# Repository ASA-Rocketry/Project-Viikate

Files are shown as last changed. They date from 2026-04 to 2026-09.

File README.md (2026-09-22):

# Project Viikate

1. Clone this repository using `git clone https://github.com/ASA-Rocketry/Project-Viikate`.
2. Open the repository in your preferred editor or just `cd` into it.
3. Run `pip install pre-commit` to install the pre-commit hook manager.
4. Run `pre-commit install --hook-type commit-msg` to activate all the local checks.
5. Run `meson setup code/build code --wipe` to generate the project compilation commands.
6. Run `meson compile -C code/build` to compile the binary. The final binary will be in `code/build/firmware/firmware`.

## Structure

```
project-viikate/
  cad/          -- the fusion files for the structure of the rocket
  code/         -- firmware, simulations and other adjacent software
    firmware/   -- the actual firmware that goes on the rocket
    dashboard/
  docs/         -- textual documentation related to the operations of the project
  minutes/      -- meeting notes
  pcb/          -- electronics, pinouts and the core PCB
```

## Software

## Style Choices

- For details on how to style your code refer to [RocketStyle](./code/README.md).
- For details on how to style your mechanical designs refer to [Mechanical Design Guide for Aalto Space Association Projects with Fusion](./cad/README.md).
- Folder names should follow `kebab-case` unless mandated by the style guide of the specific piece of software.
- Files should follow `snake_case` unless mandated by the style guide of a specific piece of software.

## Testing Policy

The priority of tests is strictly in this order:

0. Structural failures.
1. Serialization/deserialization.
2. Unit conversions.
3. Sensor fusion edgecases.
4. State machine transitions.
5. Numerical stability.
6. Watchdog/fault recovery.

Notice how getters and setters are not included. They are not important.

## How to make Git less painful

- Use rebases instead of merges. Merges pollute history, rebases straighten it back out.
- Don't commit stuff that is not supposed to be `diff`-ed. If you can't meaningfully interpret a file changing across time it should not be in git.
- Don't commit caches. Temporary files, output binaries, stuff like that.
- A commit message should follow the strict `type(scope): Message` format. This is needed to make the scope of the changes easier to understand. For example: `feat(gnc): Add the barrel roll logic`. The accepted types are as follows:
  - `feat` - a new feature, functionality that was previously missing.
  - `fix` - a fix to a bug that was causing trouble.
  - `style` - making some part of the code adhere to a style.
  - `docs` - adding documentation, amending typos.
  - `refactor` - making an old piece of code less ugly.
  - `chore` - reordering files, deleting stuff that shouldn't be tracked, etc.
- The commit text should read as what it does when applied. Not `added more tests`, but `add more tests`.
- Do not include OS-specific files in git. To exclude file locally you can add it to the `.git/info/exclude` file.

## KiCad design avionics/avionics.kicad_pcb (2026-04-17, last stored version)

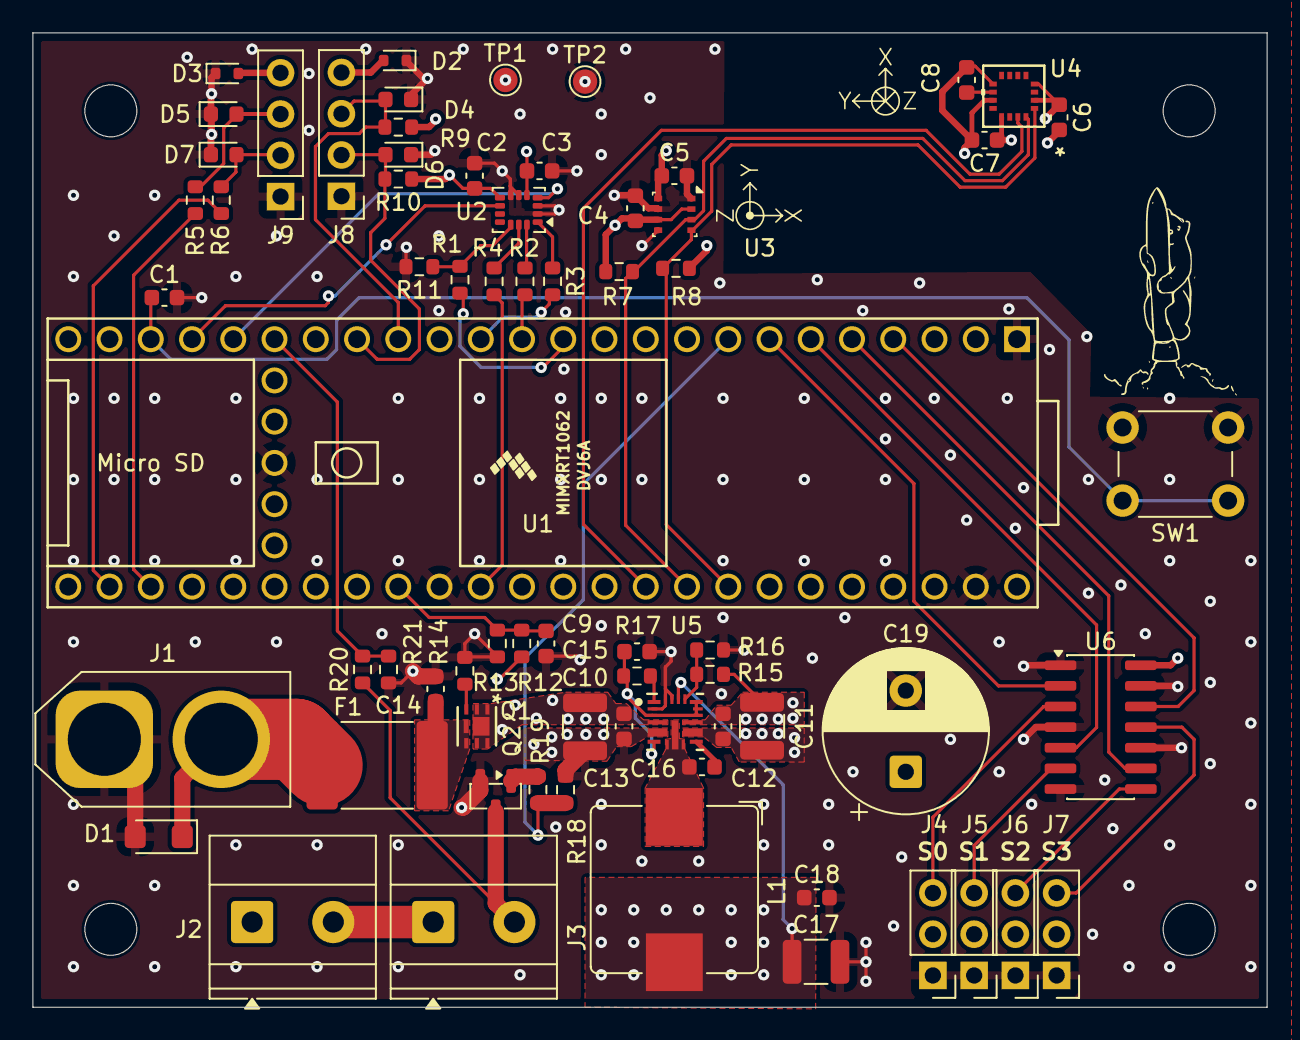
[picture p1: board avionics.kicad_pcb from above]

Board: 4 copper layers, 76.0 x 60.0 mm, 70 parts (0 on the bottom side), 49 nets.

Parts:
C1, C2, C3, C4, C5, C6, C7, C9, C14, C16: 100n; C_0603_1608Metric
C8: 10u; C_0603_1608Metric
C10, C11: 22u; C_1210_3225Metric
C12, C13, C15, C18: 1u; C_0603_1608Metric
C17: 47u; C_1210_3225Metric
C19: 1000u; CP_Radial_D10.0mm_P5.00mm
D1: SMF10A; D_SMF
D2, D3: CPDH5V0U; D_SOD-523
D4, D5, D6, D7: CPDUR5V0-HF; D_0603_1608Metric
F1: Littelfuse 2920L400; Fuse_2920_7451Metric
J1: XT60M; AMASS_XT60-M_1x02_P7.20mm_Vertical
J2, J3: 1x2_header; TerminalBlock_Phoenix_MKDS-1,5-2_1x02_P5.00mm_Horizontal
J4, J5, J6, J7: 1x3_header; PinHeader_1x03_P2.54mm_Vertical
J8, J9: Conn_01x04_Pin; PinHeader_1x04_P2.54mm_Vertical
L1: 300n; L_Bourns_SRP1038C_10.0x10.0mm
M3: MountingHole_3.2mm_M3
Q1: RF4C050AP; TRANS_RF4C_ROM
Q2: AO3400A; SOT-23
R1, R2, R3, R4, R5, R6, R19: 33; R_0603_1608Metric
R7, R8, R9, R10: 2.7k; R_0603_1608Metric
R11, R18: 100k; R_0603_1608Metric
R12, R20: 56k; R_0603_1608Metric
R13, R21: 33k; R_0603_1608Metric
R14: 47k; R_0603_1608Metric
R15: 37.4k; R_0603_1608Metric
R16, R17: 10k; R_0603_1608Metric
SW1: 6x6mm Switch; SW_PUSH_6mm
TP1: TP_3.3V; TestPoint_Pad_D1.5mm
TP2: TP_GND; TestPoint_Pad_D1.5mm
U1: Teensy4.1; Teensy41
U2: ISM330DHCX; LGA-14_3x2.5mm_P0.5mm_LayoutBorder3x4y
U3: BME280; Bosch_LGA-8_2.5x2.5mm_P0.65mm_ClockwisePinNumbering
U4: MMC5983MA; MMC5983MA_MEM
U5: TPS548B23VANR; VAN0019A-MFG
U6: 74AHCT125; SOIC-14_3.9x8.7mm_P1.27mm

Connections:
+3.3V: C2.1, C3.2, C4.1, C5.1, C6.1, C7.1, R7.1, R8.1, R9.1, R10.1, TP1.1, U1.46 (3V3), U1.51 (3V3), U2.5 (VDDIO), U2.8 (VDD), U3.2 (CSB), U3.6 (VDDIO), U3.8 (VDD), U4.2 (VDD), U4.4 (SPI_CS), U4.13 (VDDIO)
+5V: C17.1, C18.1, C19.1, J4.2, J5.2, J6.2, J7.2, L1.2, U1.48 (VIN), U5.17 (VOS_FB), U6.14 (VCC)
+BATT: C10.1, C11.1, C12.1, C13.1, J2.1, Q1.1, Q1.2, Q1.5, Q1.6, Q1.7, R12.1, R15.1, U5.4 (VIN), U5.12 (VIN)
/BAT_VOLTAGE: C9.1, R12.2, R13.1, U1.33 (41_A17)
/I2C_OUT_SCL: D4.2 (A2), J8.3, R9.2, U1.16 (24_A10_TX6_SCL2)
/I2C_OUT_SDA: D6.2 (A2), J8.2, R10.2, U1.17 (25_A11_RX6_SDA2)
/I2C_SCL: R8.2, U1.41 (19_A5_SCL), U3.4 (SCK), U4.1 (SCL/SPI_SCK)
/I2C_SDA: R7.2, U1.40 (18_A4_SDA), U3.3 (SDI), U4.16 (SDA/SPI_SDI)
/INT_ACC: U1.20 (28_RX7), U2.4 (INT1)
/INT_GYR: U1.21 (29_TX7), U2.9 (INT2)
/Magnetometer/INT: U1.39 (17_A3_TX4_SDA1), U4.15 (INT)
/PSU/BAT_CONN+: D1.1 (A1), F1.1, J1.2
/PYRO_0: R18.1, R19.2, U1.8 (6_OUT1D)
/PYRO_0_CONT: R20.2, R21.1, U1.19 (27_A13_SCK1)
/Pyro_and_servos/ARM_Vout: J2.2, J3.1
/Pyro_and_servos/PYRO_0_GATE: Q2.1 (G), R19.1
/Pyro_and_servos/PYRO_0_Vout: J3.2, Q2.3 (D), R20.1
/Pyro_and_servos/SERVO_0: J4.3, U6.3
/Pyro_and_servos/SERVO_1: J5.3, U6.6
/Pyro_and_servos/SERVO_2: J6.3, U6.8
/Pyro_and_servos/SERVO_3: J7.3, U6.11
/SERVO_0_PWM: U1.7 (5_IN2), U6.2
/SERVO_1_PWM: U1.6 (4_BCLK2), U6.5
/SERVO_2_PWM: U1.5 (3_LRCLK2), U6.9
/SERVO_3_PWM: U1.4 (2_OUT2), U6.12
/SPI_CS: R1.1, R11.1, U2.12 (CS)
/SPI_MISO: R3.1, U2.1 (SDO/SA0)
/SPI_MOSI: R2.1, U2.14 (SDA)
/SPI_SCK: R4.2, U2.13 (SCL)
/SW_GUIDANCE: C1.1, SW1.1, U1.22 (30_CRX3)
/UART_RX: D7.2 (A2), J9.2, R6.2
/UART_TX: D5.2 (A2), J9.3, R5.2
GND: C1.2, C2.2, C3.1, C4.2, C5.2, C6.2, C7.2, C8.1, C9.2, C10.2, C11.2, C12.2, C13.2, C14.2, C15.2, C17.2, C18.2, C19.2, D1.2 (A2), D2.1 (K), D3.1 (K), D4.1 (A1), D5.1 (A1), D6.1 (A1), D7.1 (A1), J1.1, J4.1, J5.1, J6.1, J7.1, J8.1, J9.1, Q2.2 (S), R11.2, R13.2, R14.2, R16.2, R18.2, R21.2, SW1.2, TP2.1, U1.1 (GND), U1.34 (GND), U1.47 (GND), U1.52 (GND), U2.2 (SDx), U2.3 (SCx), U2.6 (GND), U2.7 (GND), U3.1 (GND), U3.5 (SDO), U3.7 (GND), U4.9 (GND), U4.11 (GND), U5.2 (CFG2), U5.5 (PGND), U5.11 (PGND), U5.18 (GOS), U5.19 (AGND), U6.1, U6.4, U6.7 (GND), U6.10, U6.13
unnamed: C14.1, F1.2, Q1.4, Q1.8
unnamed: C16.2, L1.1, U5.7 (SW), U5.8 (SW), U5.9 (SW)
unnamed: D2.2 (A), J8.4
unnamed: D3.2 (A), J9.4
unnamed: Q1.3, R14.1
unnamed: R1.2, U1.12 (10_CS_MQSR)
unnamed: R2.2, U1.13 (11_MOSI_CTX1)
unnamed: R3.2, U1.14 (12_MISO_MQSL)
unnamed: R4.1, U1.35 (13_SCK_LED)
unnamed: R6.1, U1.26 (34_RX8)
unnamed: R5.1, U1.27 (35_TX8)
unnamed: C8.2, U4.10 (CAP)
unnamed: C16.1, U5.10 (BST)
unnamed: C15.1, R17.2, U5.3 (CFG1), U5.6 (VCC), U5.13 (CFG3), U5.14 (CFG4), U5.15 (CFG5)
unnamed: R15.2, R16.1, U5.16 (EN)
unnamed: R17.1, U5.1 (PG)

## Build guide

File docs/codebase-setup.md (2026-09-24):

# Codebase setup guide

Within this guide we will go over the steps of setting up the Project Viikate
codebase. You will need approximately **2 hours of time** to download and setup
everything necessary to build and flash the firmware for the avioncis unit.

## Prerequisites

Before we setup the toolchain you will need to install nix, the tool we use for
installing dependencies. While it is possible to avoid using nix, it can be
quite difficult.

### Windows users

People working on Windows will need to setup the [Windows Subsystem for Linux (WSL)](https://learn.microsoft.com/en-us/windows/wsl/install).
If you are using VSCode, it might be useful to install the [WSL Extension](https://code.visualstudio.com/docs/remote/wsl).
In order to flash the avionics board, you will have to [pass through the USB device to the VM](https://learn.microsoft.com/en-us/windows/wsl/connect-usb).

After installing WSL, you should edit the `/etc/wsl.conf` and add the following if it isn't present already (new WSL installs have this by default):
```ini
[boot]
systemd=true
```

Finally, restart the WSL virtual machine.

### Installing nix

In order to install nix, you want to [visit the nix download page](https://nixos.org/download/#nix-install-windows)
and copy and run the **multi-user installation** in the command line.

You will have to enable nix flakes by adding this to `/etc/nix/nix.conf`:
```ini
experimental-features = nix-command flakes
```

## Seting up the codebase

Quick way:
```bash
nix develop
cd code
west init -l .
west update
west zephyr-export
west build -b teensy41 app
```

Flashing:
```bash
west flash
```

Flashing and opening a serial console (the `/dev/ttyACM0` part might be different based on your system, asking ChatGPT will help if you can't find it):
```bash
west flash && sleep 1 && picocom -b 115200 /dev/ttyACM0
```

When you open a new shell (i.e. when you open VSCode for the first time), you always have to run:
```bash
nix develop
```

This is to install any dependencies.

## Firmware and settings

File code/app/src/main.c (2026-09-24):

#include <arm_math.h>
#include <assert.h>
#include <math.h>
#include <stdint.h>
#include <zephyr/drivers/pwm.h>
#include <zephyr/drivers/sensor.h>
#include <zephyr/kernel.h>
#include <zephyr/sys/printk.h>

#include "dsp/controller_functions.h"
#include "dsp/filtering_functions.h"
#include "guidance/filters.h"
#include "guidance/kalman.h"
#include "guidance/pid.h"
#include "math/linmath.h"
#include "sensors.h"
#include "servo.h"
#include "zephyr/sys/time_units.h"

#define IMU_NODE DT_NODELABEL(imu)
#define BAROMETER_NODE DT_NODELABEL(barometer)

static const struct device *imu = DEVICE_DT_GET(IMU_NODE);
static const struct device *barometer = DEVICE_DT_GET(BAROMETER_NODE);

#define STEP PWM_USEC(10)

enum direction {
    DOWN,
    UP,
};

#define TASK_BAROMETER_READ_STACK_SIZE 4096
#define TASK_BAROMETER_READ_PRIORITY 1

K_THREAD_DEFINE(
    task_barometer_read_thread_id,
    TASK_BAROMETER_READ_STACK_SIZE,
    task_barometer_read,
    &barometer,
    NULL,
    NULL,
    TASK_BAROMETER_READ_PRIORITY,
    0,
    0
);

static int sweep_servo(const servo_t servo) {
    float angle = -90.0f;  // start at minimum position
    enum direction dir = UP;
    int ret;

    printk("Servomotor control (angle based)\n");

    if (!pwm_is_ready_dt(&servo.spec)) {
        printk("Error: PWM device %s is not ready\n", servo.spec.dev->name);
        return -ENODEV;
    }

    while (1) {
        ret = servo_set_angle(servo, angle);
        if (ret < 0) {
            printk("Error %d: failed to set angle %.1f\n", ret, (double)angle);
            return ret;
        }

        // Step size = degrees per iteration
        const float step_size = 1.0f;

        if (dir == UP) {
            angle += step_size;
            if (angle >= 90.0f) {
                angle = 90.0f;
                dir = DOWN;
            }
        } else {
            angle -= step_size;
            if (angle <= -90.0f) {
                angle = -90.0f;
                dir = UP;
            }
        }

        k_sleep(K_MSEC(20));  // Smooth sweep speed
    }

    return 0;
}

double pressure_to_altitude(double pressure_pa) {
    const double P0 = 101325.0;  // Sea level pressure (Pa)
    const double T0 = 288.15;  // Sea level temperature (K)
    const double L = 0.0065;  // Temperature lapse rate (K/m)
    const double g = 9.80665;  // Gravity (m/s²)
    const double R = 287.05;  // Specific gas constant (J/(kg·K))

    // Barometric formula: h = (T0 / L) * (1 - (P / P0)^(R*L/g))
    double exponent = (R * L) / g;
    double altitude = (T0 / L) * (1.0 - pow(pressure_pa / P0, exponent));

    return altitude;
}

void print_acceleration(const imu_sample_t *sample) {
    printf(
        "Acceleration [m/s²]: X=%f, Y=%f, Z=%f\n",
        (double)sample->acceleration[0],
        (double)sample->acceleration[1],
        (double)sample->acceleration[2]
    );
}

void transform_coords(imu_sample_t *imu_sample) {
    vec3 acc_old;
    vec3 gyro_old;
    vec3_dup(acc_old, imu_sample->acceleration);
    vec3_dup(gyro_old, imu_sample->angular_rate);

    imu_sample->acceleration[0] = -acc_old[2];
    imu_sample->acceleration[1] = acc_old[1];
    imu_sample->acceleration[2] = acc_old[0];

    imu_sample->angular_rate[0] = -gyro_old[2];
    imu_sample->angular_rate[1] = gyro_old[1];
    imu_sample->angular_rate[2] = gyro_old[0];
}

LINMATH_H_FUNC float quat_get_roll(quat const q) {
    float x = q[0];
    float y = q[1];
    float z = q[2];
    float w = q[3];

    float siny_cosp = 2.f * (w * z + x * y);
    float cosy_cosp = 1.f - 2.f * (y * y + z * z);

    return atan2f(siny_cosp, cosy_cosp);
}

int main(void) {
    barometer_init(barometer);
    imu_init(imu);

    imu_sample_t imu_sample;
    barometer_sample_t baro_sample;
    int ret;

    assert(imu_filter != NULL);

    float drift_last = 0.0f;

    vec3 avg_accel = {0}, avg_gyro = {0};

    vec3 g = {0};
#define AVG_COUNT 256
    for (int k_idx = 0; k_idx < AVG_COUNT; ++k_idx) {
        ret = k_msgq_get(&imu_msgq, &imu_sample, K_FOREVER);
        transform_coords(&imu_sample);
        vec3_add(g, g, imu_sample.acceleration);
    }
    vec3_scale(g, g, 1.0f / AVG_COUNT);

    kalman_filter_t k = kalman_init(g);

#define AVG_COUNT 256
    for (int k_idx = 0; k_idx < AVG_COUNT; ++k_idx) {
        ret = k_msgq_get(&imu_msgq, &imu_sample, K_FOREVER);
        transform_coords(&imu_sample);
        vec3 a;
        vec3_sub(a, imu_sample.acceleration, g);

        vec3_add(avg_accel, avg_accel, a);
        vec3_add(avg_gyro, avg_gyro, imu_sample.angular_rate);
    }

    vec3_scale(avg_accel, avg_accel, 1.0f / AVG_COUNT);
    vec3_scale(avg_gyro, avg_gyro, 1.0f / AVG_COUNT);

    vec3_dup(k.gyroscope_bias, avg_gyro);
    vec3_dup(k.accelerometer_bias, avg_accel);

    float base_altitude = 0.0f;
    for (int k_idx = 0; k_idx < 8; ++k_idx) {
        ret = k_msgq_get(&barometer_msgq, &baro_sample, K_FOREVER);

        base_altitude += pressure_to_altitude((double)baro_sample.pressure);
    }

    base_altitude *= 1.0f / 8;

    uint32_t loop_counter = 0;
    uint64_t time = 0;
    int loops = 0;

    roll_control_reset();

    while (1) {
        uint64_t start = k_ticks_to_ns_floor64(k_uptime_ticks());

        /* Read IMU if data is available */
        while ((ret = k_msgq_get(&imu_msgq, &imu_sample, K_NO_WAIT)) == 0) {
            transform_coords(&imu_sample);
            ekf_predict(&k, imu_sample);
            loops++;
        }

        time += k_ticks_to_ns_floor64(k_uptime_ticks()) - start;

        while ((ret = k_msgq_get(&barometer_msgq, &baro_sample, K_NO_WAIT))
               == 0) {
            float altitude = (float)pressure_to_altitude(baro_sample.pressure)
                - base_altitude;
            k.position[1] = altitude;
        }

        /* Print state every 500 iterations (~500 ms at 1 kHz) */
        if (loop_counter % 500 == 0) {
            printk(
                "loops: %d total_time: %f time_per_kalman: %f\n",
                loops,
                (double)((float)time * 1e-9f),
                (double)((float)time * 1e-9f / (float)(loops > 0 ? loops : 1))
            );
            printk(
                "STATE:\n"
                "    pos = [%.3f, %.3f, %.3f]\n"
                "    vel = [%.3f, %.3f, %.3f]\n"
                "    ori = [%.4f, %.4f, %.4f, %.4f]\n"
                "    ang_vel = [%.4f, %.4f, %.4f]\n"
                "    acc_bias = [%.4f, %.4f, %.4f]\n"
                "    gyro_bias = [%.4f, %.4f, %.4f]\n"
                "    g = %.4f\n"
                "    t_last = %llu ns\n",
                (double)k.position[0],
                (double)k.position[1],
                (double)k.position[2],
                (double)k.velocity[0],
                (double)k.velocity[1],
                (double)k.velocity[2],
                (double)k.orientation[0],
                (double)k.orientation[1],
                (double)k.orientation[2],
                (double)k.orientation[3],
                (double)k.angular_velocity[0],
                (double)k.angular_velocity[1],
                (double)k.angular_velocity[2],
                (double)k.accelerometer_bias[0],
                (double)k.accelerometer_bias[1],
                (double)k.accelerometer_bias[2],
                (double)k.gyroscope_bias[0],
                (double)k.gyroscope_bias[1],
                (double)k.gyroscope_bias[2],
                (double)k.gravity,
                (unsigned long long)k.last_measurement_timestamp_ns
            );
            loops = 0;
        }

        static uint64_t last_roll_update_ns;

        if (loop_counter % 20 == 0) {
            uint64_t now = k_ticks_to_ns_floor64(k_uptime_ticks());
            float dt = last_roll_update_ns == 0
                ? 0.02f
                : (float)(now - last_roll_update_ns) * 1e-9f;
            last_roll_update_ns = now;

            roll_control_update(quat_get_roll(k.orientation), 0.0f, dt);
        }

        loop_counter++;
        k_sleep(K_MSEC(1));  // 1 kHz update rate
    }
}

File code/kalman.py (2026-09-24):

import serial
import re
import math
from collections import deque
import numpy as np
import matplotlib.pyplot as plt
import matplotlib.animation as animation
from matplotlib.gridspec import GridSpec
from mpl_toolkits.mplot3d import Axes3D
import threading


class KalmanVisualizer:
    def __init__(self, port="/dev/ttyACM0", baudrate=115200):
        self.port = port
        self.baudrate = baudrate
        self.serial = None
        self.max_history = 200

        self.history = {
            "pos": deque(maxlen=self.max_history),
            "vel": deque(maxlen=self.max_history),
            "euler": deque(maxlen=self.max_history),
            "ori": deque(maxlen=self.max_history),
            "ang_vel": deque(maxlen=self.max_history),
            "acc_bias": deque(maxlen=self.max_history),
            "gyro_bias": deque(maxlen=self.max_history),
            "time_per_kalman": deque(maxlen=self.max_history),
        }

        self.setup_plots()

    def connect(self):
        try:
            self.serial = serial.Serial(self.port, self.baudrate, timeout=1)
            print(f"Connected to {self.port}")
            return True
        except Exception as e:
            print(f"Failed to connect: {e}")
            return False

    def quaternion_to_euler(self, quat):
        """Convert quaternion [qx, qy, qz, qw] to Euler angles (degrees)"""
        qx, qy, qz, qw = quat

        sinr_cosp = 2 * (qw * qx + qy * qz)
        cosr_cosp = 1 - 2 * (qx * qx + qy * qy)
        roll = math.atan2(sinr_cosp, cosr_cosp)

        sinp = 2 * (qw * qy - qz * qx)
        pitch = math.asin(min(1, max(-1, sinp)))

        siny_cosp = 2 * (qw * qz + qx * qy)
        cosy_cosp = 1 - 2 * (qy * qy + qz * qz)
        yaw = math.atan2(siny_cosp, cosy_cosp)

        return [math.degrees(roll), math.degrees(pitch), math.degrees(yaw)]

    def quaternion_to_rotation_matrix(self, quat):
        """Convert quaternion to 3x3 rotation matrix"""
        qx, qy, qz, qw = quat

        R = np.array(
            [
                [
                    1 - 2 * (qy**2 + qz**2),
                    2 * (qx * qy - qz * qw),
                    2 * (qx * qz + qy * qw),
                ],
                [
                    2 * (qx * qy + qz * qw),
                    1 - 2 * (qx**2 + qz**2),
                    2 * (qy * qz - qx * qw),
                ],
                [
                    2 * (qx * qz - qy * qw),
                    2 * (qy * qz + qx * qw),
                    1 - 2 * (qx**2 + qy**2),
                ],
            ]
        )

        return R

    def setup_plots(self):
        """Setup matplotlib dashboard"""
        self.fig = plt.figure(figsize=(18, 10))
        self.fig.suptitle("Kalman Filter State Monitor", fontsize=16, fontweight="bold")

        gs = GridSpec(3, 4, figure=self.fig, hspace=0.3, wspace=0.3)

        self.ax_3d = self.fig.add_subplot(gs[0:2, 0], projection="3d")
        self.ax_pos = self.fig.add_subplot(gs[0, 1:3])
        self.ax_vel = self.fig.add_subplot(gs[1, 1:3])
        self.ax_euler = self.fig.add_subplot(gs[2, 1:3])

        self.ax_ang_vel = self.fig.add_subplot(gs[0, 3])
        self.ax_acc_bias = self.fig.add_subplot(gs[1, 3])
        self.ax_gyro_bias = self.fig.add_subplot(gs[2, 3])

        self.ax_stats = self.fig.add_axes([0.02, 0.02, 0.15, 0.15])
        self.ax_stats.axis("off")
        self.stats_text = self.ax_stats.text(
            0,
            1,
            "Waiting for data...",
            transform=self.ax_stats.transAxes,
            fontsize=9,
            verticalalignment="top",
            fontfamily="monospace",
        )

        self.ax_3d.set_xlabel("X")
        self.ax_3d.set_ylabel("Y")
        self.ax_3d.set_zlabel("Z")
        self.ax_3d.set_title("3D Orientation")
        self.ax_3d.set_xlim([-1.5, 1.5])
        self.ax_3d.set_ylim([-1.5, 1.5])
        self.ax_3d.set_zlim([-1.5, 1.5])

    def draw_3d_frame(self, ax, rotation_matrix):
        """Draw coordinate frame on 3D axis"""
        ax.clear()

        origin = np.array([0, 0, 0])

        x_axis = np.array([1, 0, 0])
        y_axis = np.array([0, 1, 0])
        z_axis = np.array([0, 0, 1])

        x_rotated = rotation_matrix @ x_axis
        y_rotated = rotation_matrix @ y_axis
        z_rotated = rotation_matrix @ z_axis

        ax.quiver(
            0,
            0,
            0,
            x_rotated[0],
            x_rotated[1],
            x_rotated[2],
            color="r",
            arrow_length_ratio=0.2,
            linewidth=2.5,
            label="X",
        )
        ax.quiver(
            0,
            0,
            0,
            y_rotated[0],
            y_rotated[1],
            y_rotated[2],
            color="g",
            arrow_length_ratio=0.2,
            linewidth=2.5,
            label="Y",
        )
        ax.quiver(
            0,
            0,
            0,
            z_rotated[0],
            z_rotated[1],
            z_rotated[2],
            color="b",
            arrow_length_ratio=0.2,
            linewidth=2.5,
            label="Z",
        )

        ax.set_xlabel("X")
        ax.set_ylabel("Y")
        ax.set_zlabel("Z")
        ax.set_xlim([-1.5, 1.5])
        ax.set_ylim([-1.5, 1.5])
        ax.set_zlim([-1.5, 1.5])
        ax.set_title("3D Orientation")
        ax.legend(fontsize=10)

    def parse_state(self, lines):
        """Parse STATE block from list of lines"""
        state = {}

        for line in lines:
            line = line.strip()
            if not line or line.startswith("STATE"):
                continue

            if "=" in line:
                key, value = line.split("=", 1)
                key = key.strip()
                value = value.strip()

                try:
                    if "[" in value and "]" in value:
                        nums = re.findall(r"-?\d+\.?\d*", value)
                        state[key] = [float(n) for n in nums]
                    else:
                        state[key] = float(value)
                except ValueError:
                    pass

        return state

    def update_data(self, state, time_per_kalman):
        """Add new state to history"""
        if "pos" in state:
            self.history["pos"].append(state["pos"])
        if "vel" in state:
            self.history["vel"].append(state["vel"])
        if "ori" in state:
            self.history["ori"].append(state["ori"])
            euler = self.quaternion_to_euler(state["ori"])
            self.history["euler"].append(euler)
        if "ang_vel" in state:
            self.history["ang_vel"].append(state["ang_vel"])
        if "acc_bias" in state:
            self.history["acc_bias"].append(state["acc_bias"])
        if "gyro_bias" in state:
            self.history["gyro_bias"].append(state["gyro_bias"])

        self.history["time_per_kalman"].append(time_per_kalman * 1e6)
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

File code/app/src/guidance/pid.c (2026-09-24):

#include "guidance/pid.h"

#include "zephyr/kernel.h"
#include "zephyr/sys/printk.h"

static const servo_t servo0 = DT_SERVO_GET(DT_NODELABEL(servo0));
static const servo_t servo1 = DT_SERVO_GET(DT_NODELABEL(servo1));
static const servo_t servo2 = DT_SERVO_GET(DT_NODELABEL(servo2));
static const servo_t servo3 = DT_SERVO_GET(DT_NODELABEL(servo3));

/* ---------- Servo trim / neutral positions ---------- */
#define SERVO0_NEUTRAL 0.0f
#define SERVO1_NEUTRAL 0.0f
#define SERVO2_NEUTRAL 0.0f
#define SERVO3_NEUTRAL 0.0f

#define SERVO_MIN_ANGLE -90.0f
#define SERVO_MAX_ANGLE 90.0f

/* ---------- PID state ---------- */
static pid_t roll_pid = {
    .kp = 0.1745f * 180.0f / 3.14f,
    .ki = 0.0f,
    .kd = 0.09f * 180.0f / 3.14f,
    .integral = 0.0f,
    .prev_error = 0.0f,
    .integral_limit = 20.0f,
    .output_limit = 45.0f,
    .initialized = false,
};

/* ---------- Helpers ---------- */
static float clampf(float val, float min, float max) {
    if (val < min)
        return min;
    if (val > max)
        return max;
    return val;
}

static void pid_reset(pid_t *pid) {
    pid->integral = 0.0f;
    pid->prev_error = 0.0f;
    pid->initialized = false;
}

/*
 * Update PID controller.
 * error: target - current (degrees)
 * dt: time since last update (seconds)
 * returns: correction output (degrees), clamped to output_limit
 */
static float pid_update(pid_t *pid, float error, float dt) {
    if (dt <= 0.0f) {
        dt = 1e-3f; /* avoid div-by-zero */
    }

    /* Integral term with anti-windup */
    pid->integral += error * dt;
    pid->integral =
        clampf(pid->integral, -pid->integral_limit, pid->integral_limit);

    /* Derivative term (skip on first sample to avoid spike) */
    float derivative = 0.0f;
    if (pid->initialized) {
        derivative = (error - pid->prev_error) / dt;
    } else {
        pid->initialized = true;
    }
    pid->prev_error = error;

    float output =
        (pid->kp * error) + (pid->ki * pid->integral) + (pid->kd * derivative);

    return clampf(output, -pid->output_limit, pid->output_limit);
}

void roll_control_reset(void) {
    pid_reset(&roll_pid);
}

/*
 * Roll control update.
 *
 * Assumes servo0/servo1 are on one side and servo2/servo3 are on the
 * opposite side, moving in mirrored fashion to correct roll (differential
 * mixing). Adjust the sign/mapping to match your mechanism.
 */
void roll_control_update(float current_roll, float target_roll, float dt) {
    float error = target_roll - current_roll;
    printk("erorr %f\n", (double)error);

    float correction = pid_update(&roll_pid, error, dt);

    float angle0 = SERVO0_NEUTRAL + correction;
    float angle1 = SERVO1_NEUTRAL + correction;
    float angle2 = SERVO2_NEUTRAL - correction;
    float angle3 = SERVO3_NEUTRAL - correction;

    angle0 = clampf(angle0, SERVO_MIN_ANGLE, SERVO_MAX_ANGLE);
    angle1 = clampf(angle1, SERVO_MIN_ANGLE, SERVO_MAX_ANGLE);
    angle2 = clampf(angle2, SERVO_MIN_ANGLE, SERVO_MAX_ANGLE);
    angle3 = clampf(angle3, SERVO_MIN_ANGLE, SERVO_MAX_ANGLE);

    uint64_t t_before = k_ticks_to_ns_floor64(k_uptime_ticks());
    servo_set_angle(servo0, angle0);
    servo_set_angle(servo1, angle1);
    servo_set_angle(servo2, angle2);
    servo_set_angle(servo3, angle3);
    uint64_t t_after = k_ticks_to_ns_floor64(k_uptime_ticks());
    uint64_t roll_dt = t_after - t_before;

    static uint64_t roll_dt_max = 0;
    if (roll_dt > roll_dt_max) {
        roll_dt_max = roll_dt;
        printk(
            "NEW MAX roll_control_update: %llu ns at loop \n",
            (unsigned long long)roll_dt
        );
    }
}

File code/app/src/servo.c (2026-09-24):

#include "servo.h"

#include <math.h>

#include "zephyr/drivers/pwm.h"

int servo_set_angle(const servo_t servo, float angle) {
    float clamped = fminf(fmaxf(angle, -90.0f), 90.0f);
    float percent = (clamped + 90.0f) / 180.f;
    float range = (float)(servo.max_pulse - servo.min_pulse);
    uint32_t pulse = (uint32_t)(range * percent) + servo.min_pulse;

    int ret = pwm_set_pulse_dt(&servo.spec, pulse);
    return ret;
}

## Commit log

2026-03-22 Added Openrocket V0.4
    Corrected dimensions and weights to match CAD files.
2026-03-24 FIle renaming to follow snake case.
2026-03-25 Add files via upload
    Sensor readout testing
2026-03-30 Modified FlightData-Struct to accomodate all sensor axes
2026-03-30 Changed FlightData-struct variable naming convention, fixed all the constant calls to use the new names and fixed a couple of typos
2026-03-31 Added IMU calibration
    Added imucalattempt.ino. This should help calibrate the IMU. Tested and works (kind of), will improve on when I can
2026-04-01 Implemented the PID with antiwindup and control_hardware class
2026-04-06 Fixed the servo.h-library problem. PIO scans lib_deps first, before any specific board-libraries, so the built in teensy servo-library got overwritten by the uno-library -> incompatibility. Removed u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
2026-04-08 migrating avionics system to platform.io, got working sensor readings and compatibility with gnc's testbench
2026-04-16 Modified sensors.cpp and main.cpp for exception handling and imu/mag data
    Magnetometer data isn't being saved in FlightData/not being printed. figuring out why
2026-04-16 changed sensors class to call read functions minimally
2026-04-16 Edited such that magnetometer readings can be taken!
    Previously on the serial monitor magnetometer readings were showing up as 0.0, 0.0, 0.0. Problem was due to a float precision issue
2026-04-16 fixed imu buffering issue
2026-04-17 fixed axis on the pcb
    [avionics.kicad_pcb]
2026-04-17 fixed axis issue to make sure all sensor z-axes point "up"
2026-04-17 added ArduinoEigen dependency
2026-04-19 created class structure for kalman filter
2026-04-19 Updated sensors.cpp, currently trying to test kalman filter
2026-04-20 Updated to include Kalman filter for accelerometer
    THE KALMAN FILTER WORKS!!! to tweak to account for gravity, will implement for gyroscope as well
2026-04-20 added gyroscope kalman filter, need to fix scaling issues and gravity offsets
2026-04-20 minor bug fixes, current orientation readings are in radians
2026-04-20 fixed servo library build issues
2026-04-20 calibration works
2026-04-20 updated sensors to include kalman filter for accX and accY
    Kalman filter has also been implemented for X axis and Y axis acceleration data. Will need to test tomorrow, publishing in a separate branch for now
2026-04-21 Updated PID constants
    Made changes to accelerometer kalman filter matrices and updated PID constants
2026-04-21 Updated PID values and control of D value
    Updated PID values. D value adjusted such that D=0 when error difference is less than 2deg
2026-04-26 kinda working wind tunnel PID, made tweaks to d-term handling
2026-05-04 Renaming PID constants, for future roll, pitch and yaw implementation.
2026-05-04 Added a test enviroment and a test code. corrently doesn't work with out hardware attached.
2026-05-06 Reverted the test environment, and added a simulated_flight_data_1.csv, now we need to implement precompile flags, to run the statemachine with fake data.
    [simulated_flight_data_1.csv]
2026-05-06 Testing Simulated data reading and execution.
    [simulated_flight_data_1.csv]
2026-05-06 Currently doesn't show simulated data correctly.
2026-05-07 Added a "calibration and PID test" environment, which is equal to our previous pid simulations, and production flight mode. still debugging sd card reading
2026-05-08 Enviroments work now, and each initialization returns and prints.
    [simulated_flight_data_1.csv]
2026-05-08 Added accessors and integrated the state machine into TEST_STATE_MACHINE mode. Initialization checks still need to be implemented in the Sensors module, following the same pattern as DataLogger, to e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
2026-05-11 Implemented final initialization checks for the Calibration state, fixed spelling mistakes, ect.
2026-05-12 Simplified the setup in Main.cpp and the servo naming. Both have been tested and work.
2026-05-12 Fixed the servo offset.
2026-05-19 Expanded debug prints, by making it a header, and including it everywhere. Also added a "non functioning" check to sensors for future implementation.
2026-05-26 Wipe everything
    [avionics.kicad_pcb, avionics.kicad_sch, barometer.kicad_sch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]
2026-09-24 sensors proper
2026-09-24 ekf very sloppy pls squash full branch
    [main.c]
2026-09-24 ekf less slop no update
    [kalman.py, linmath.h, main.c]
2026-11-13 feat(hil): Add hardware-in-the-loop boot test
    Run the flight application on a Teensy 4.1 attached to the rig with
    twister device testing. The test flashes the image, cuts and restores
    USB power to force a cold boot, then checks that the board enumerates
    with the console VID:PID and stays up without a fatal error.
    Application sources move to sources.cmake so the test build compiles
    exactly the same code as code/app.
2026-11-13 feat(log): Add non-blocking ring buffer logger
    viikate::log (viikate_log from C) copies a message into a RAM ring buffer
    under a spinlock and wakes a low priority thread that writes whole lines
    to the console. Callers never wait on the console, so it is safe to use
    from control loops and ISRs. When the buffer is full the message is
    dropped and the flush thread reports how many were lost.
2026-11-13 fix(app): Boot and idle without the sensor board attached
    With nothing on the I2C bus the open-drain lines float low and the BME280
    probe never returns, so boot stops before USB comes up. Enable the internal
    pull-ups so the probe fails cleanly instead. The barometer task now waits
    for the device instead of printing a fetch error every millisecond.
2026-11-13 feat(app): Reboot into the bootloader at 134 baud
    Opening the console at 134 baud reboots into HalfKay, the same convention
    as Teensyduino, so the board can be reflashed without pressing PROGRAM.
2026-11-13 feat(log): Log any standard type and keep logs on flash
    viikate_log() takes any mix of strings, chars, bools, integers, floats and
    pointers, separated by spaces, from C (_Generic) and C++ (variadic template).
    A line is handed to the flush thread only once it is complete and newline
    terminated. The flush thread also appends it to /lfs/log.txt on a littlefs
    partition in the onboard flash and syncs, so logs survive power loss. The
    file rotates at 64 KiB, keeping four files.
    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
2026-11-13 test(hil): Check that logs survive power cuts and rotate
    A second scenario builds the application with a shell on the console. The
    test reads the log files back with fs cat across USB power cuts and fills
    the log past its size limit to check rotation keeps every line intact.
    rig.sh flash uses the 134-baud reboot, so runs no longer need PROGRAM.
